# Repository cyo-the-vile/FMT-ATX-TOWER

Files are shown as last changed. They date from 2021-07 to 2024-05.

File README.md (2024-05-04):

# FMT-ATX-TOWER
A modification to revive a dead FM Towns tower model

[https://townsworld.com/2021/05/08/fm-towns-tower-power-supply-assembly-guide/](https://web.archive.org/web/20230320093739/https://townsworld.com/2021/05/08/fm-towns-tower-power-supply-assembly-guide/)

Uses an Arduino PRO Micro to control power on and TownsOS power off functions just like the original power supply.

Some of the mounting holes might not be exact.  At a later time, I need to measure the holes again but I don't own an original PCB anymore.  It is safe to file and cut around the screw points on the outer edges.

To order a PCB, go to factory output folder and select the RAR file.

Works on the following models:

1F
2F
SF
SH
1H
2H
10F
20F
40H
80H
SF2
SH2
CX10
CX20
CX40
CX100

It WILL NOT WORK for the following models:

S1
S2
MODEL1
MODEL2

You will need the following parts:

1    PCN13-44S-2.54DS
1	 39-28-1243    or you can use 39-28-1203.    It is preferred to use 39-28-1243
1    Arduino Pro Micro and Micro USB cable.  You need to load the firmware for the Arduino Pro Micro
1    Some male 2.54mm pin headers.
1    Pico PSU rated at 90W or higher such as this one   https://www.mini-box.com/picoPSU-90     The prototype was tested with 160W but I have found 90W is fine.
		Pico PSU have been cloned and their performance might vary. I recommend using the authentic mini-box brand.
1    AC/DC Converter.  The board can physically fit the EPS-120-12 or the EPS-120S-12.  Basically, an ACDC Converter that outputs 12V in a 2x3 or 2x4 (those are inches) form factor is fine.

日本人にとって、機械翻訳です。 あなたが困難を持っている場合は、Twitterで私に連絡してください。@cyothevile

死んだFMタウンズタワーモデルを復活させるための修正

[https://townsworld.com/2021/05/08/fm-towns-tower-power-supply-assembly-guide/](https://web.archive.org/web/20230320093739/https://townsworld.com/2021/05/08/fm-towns-tower-power-supply-assembly-guide/)

Arduino PRO Microを使用して、元の電源と同様に電源オンとTownsOSの電源オフ機能を制御します。

取り付け穴の中には、正確でないものもあります。 後で、私は再び穴を測定する必要がありますが、私はもう元のPCBを所有していません。 外縁のネジ点の周りをヤスリで留めて切断しても安全です。

PCBを注文するには、工場出荷時の出力フォルダに移動し、RARファイルを選択します。

次のモデルで動作します。

1F
2F
SF
SH
1H
2H
10F
20F
40H
80H
SF2
SH2
CX10
CX20
CX40
CX100

次のモデルでは動作しません。

S1
S2 
モデル1 or Model 1
モデル2 or Model 2

次の部品が必要です。

次の部品が必要です。

1 PCN13-44S-2.54DS
1 39-28-1243 または 39-28-1203 を使用できます。   39-28-1243 を使用することをお勧めします。
1 ArduinoプロマイクロとマイクロUSBケーブル。 Arduinoプロマイクロのファームウェアをロードする必要があります
1 いくつかのオス2.54mmピンヘッダー。
1 Pico PSUは、このような90W以上で定格 https://www.mini-box.com/picoPSU-90 プロトタイプは160Wでテストされましたが、90Wは問題ありません。
		Pico PSUはクローン化されており、それらのパフォーマンスは異なる場合があります。私は本物のミニボックスブランドを使用することをお勧めします。
1 AC / DCコンバータ。 ボードはEPS-120-12またはEPS-120S-12に物理的にフィットすることができます。 基本的に、2x3または2x4(これらはインチ)のフォームファクタで12Vを出力するACDCコンバータは問題ありません。

******************************************************

Generation 1 Tower card 

 - Requires more testing.  Should be safe for testing.

Please follow precise instructions here:  [https://townsworld.com/2021/06/01/fm-towns-power-supply-generation-1/](https://web.archive.org/web/20230603034252/https://townsworld.com/2021/06/01/fm-towns-power-supply-generation-1/)

VMS-180C-12
VOF-180C-12
VMS-200C-12

These are the recommended ACDC converters to place on the card.  The Generation 1 Towers appear to use more power.  A 160W Pico is recommended until further testing is completed.

ジェネレーション1タワーカード

日本人の友達、困ったら連絡してください。 TWITTER@cyo.the.vile

- さらにテストが必要です。テストのために安全でなければなりません。

こちらの正確な指示に従ってください: [https://townsworld.com/2021/06/01/fm-towns-power-supply-generation-1/](https://web.archive.org/web/20230603034252/https://townsworld.com/2021/06/01/fm-towns-power-supply-generation-1/)

VMS-180C-12
VOF-180C-12
VMS-200C-12

これらは、カードに配置する推奨 ACDC コンバータです。第 1 世代のタワーは、より多くの電力を使用しているようです。 さらなるテストが完了するまでは、160W Pico をお勧めします。

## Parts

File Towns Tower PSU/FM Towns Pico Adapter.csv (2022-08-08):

Id | Designator | Package | Quantity | Designation | Supplier and ref
1 | PAD1,PAD1,PAD1,PAD2,PAD1,PAD3,PAD4 | MountingHole_3.5mm_Pad_Via | 7 | MountingHole_3.5mm_Pad_Via
2 | U1 | ProMicro | 1 | ProMicro
3 | REF**,REF**,REF** | MountingHole_2.1mm | 3 | MountingHole_2.1mm
4 | REF**,REF**,REF**,REF**,REF**,REF** | MountingHole_4.3mm_M4 | 6 | MountingHole_4.3mm_M4
5 | STOCK_FAN | PinHeader_1x02_P2.54mm_Vertical | 1 | Conn_01x02
6 | J1 | ATX24_RIGHT_ANGLE | 1 | ATX24RH
7 | G*** | townslogo | 1 | LOGO
8 | J2 | PCN1344S254DS71 | 1 | PCN13-44S-2.54DS_71_

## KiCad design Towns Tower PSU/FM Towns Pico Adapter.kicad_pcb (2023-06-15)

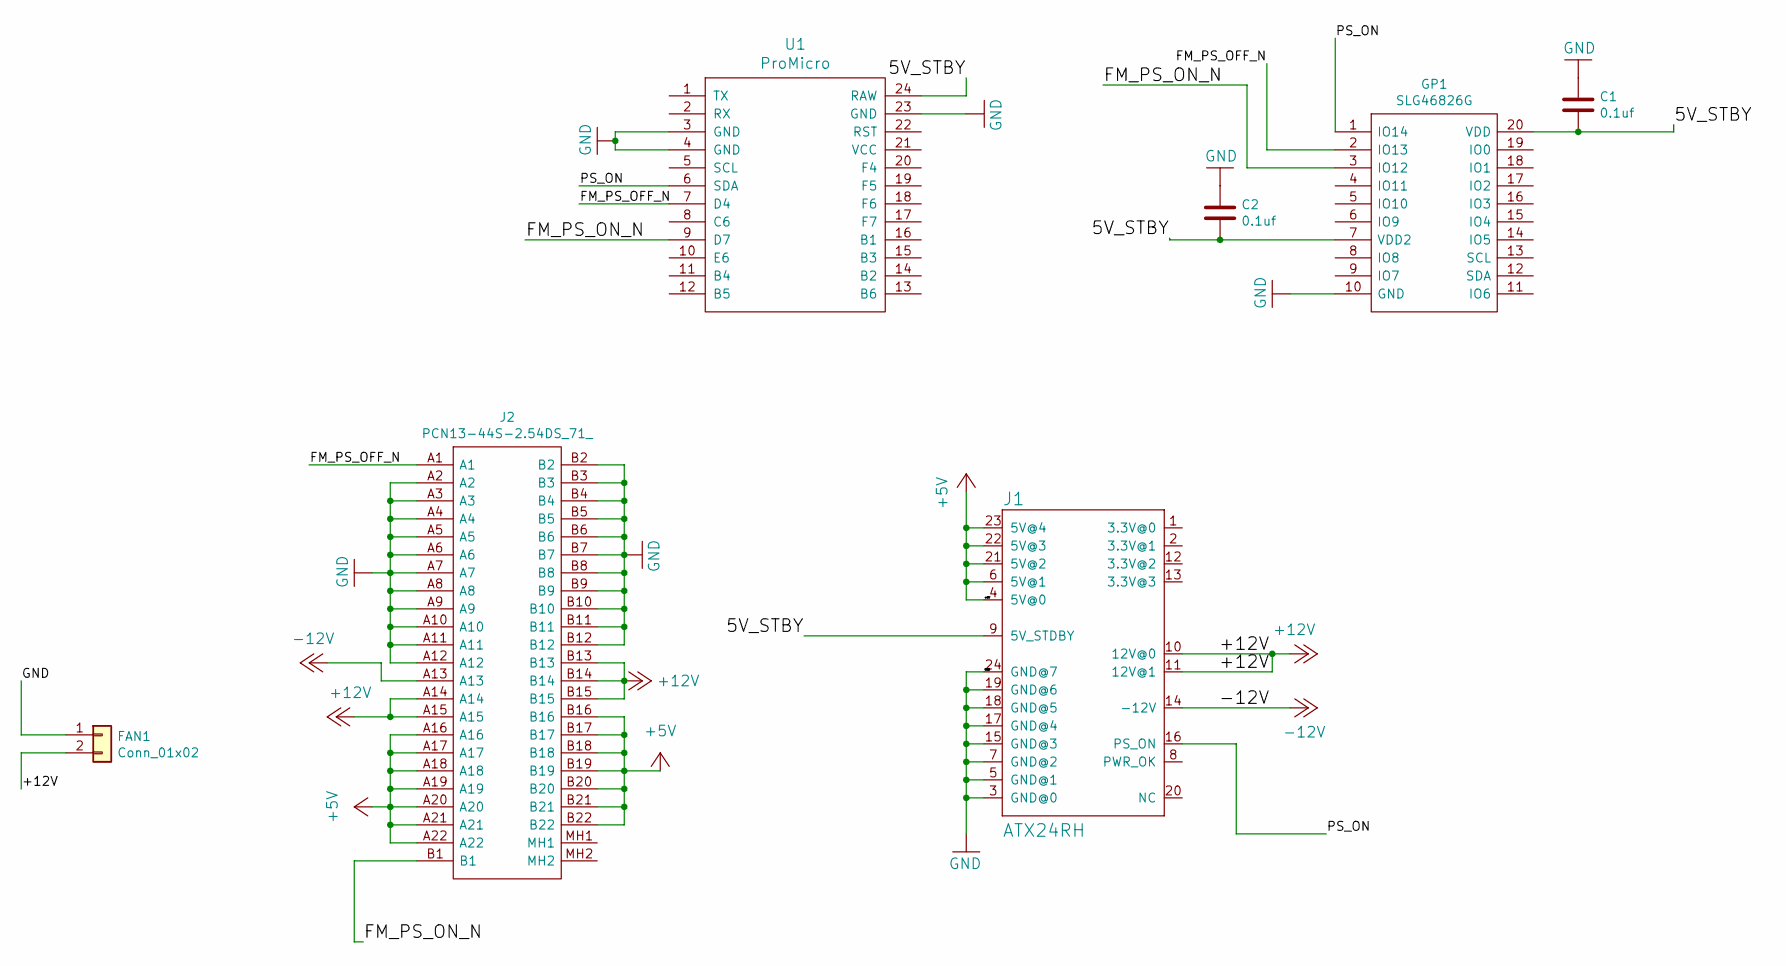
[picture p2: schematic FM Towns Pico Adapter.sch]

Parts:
C1, C2: 0.1uf; C_1206_3216Metric
FAN1: Conn_01x02; PinHeader_1x02_P2.54mm_Vertical
GP1: SLG46826G; SOP65P640X120-20N; Manufacturer_Part_Number SLG46826G; Mouser Part Number 724-SLG46826G
J1: ATX24RH; ATX24_RIGHT_ANGLE
J2: PCN13-44S-2.54DS_71_; PCN1344S254DS71; Manufacturer_Part_Number PCN13-44S-2.54DS(71); Mouser Part Number 798-PCN1344S254DS71
U1: ProMicro

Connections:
+5V: J1.4 (5V@0), J1.6 (5V@1), J1.21 (5V@2), J1.22 (5V@3), J1.23 (5V@4), J2.A16, J2.A17, J2.A18, J2.A19, J2.A20, J2.A21, J2.A22, J2.B16, J2.B17, J2.B18, J2.B19, J2.B20, J2.B21, J2.B22
+12V: FAN1.2, J1.10 (12V@0), J1.11 (12V@1), J2.A14, J2.A15, J2.B13, J2.B14, J2.B15
-12V: J1.14 (-12V), J2.A13
/5V_STBY: C1.2, C2.2, GP1.7 (VDD2), GP1.20 (VDD), J1.9 (5V_STDBY), U1.24 (RAW)
/FM_PS_OFF_N: GP1.2 (IO13), J2.A1, U1.7 (D4)
/FM_PS_ON_N: GP1.3 (IO12), J2.B1, U1.9 (D7)
/PS_ON: GP1.1 (IO14), J1.16 (PS_ON), U1.6 (SDA)
GND: C1.1, C2.1, FAN1.1, GP1.10 (GND), J1.3 (GND@0), J1.5 (GND@1), J1.7 (GND@2), J1.15 (GND@3), J1.17 (GND@4), J1.18 (GND@5), J1.19 (GND@6), J1.24 (GND@7), J2.A2, J2.A3, J2.A4, J2.A5, J2.A6, J2.A7, J2.A8, J2.A9, J2.A10, J2.A11, J2.A12, J2.B2, J2.B3, J2.B4, J2.B5, J2.B6, J2.B7, J2.B8, J2.B9, J2.B10, J2.B11, J2.B12, U1.3 (GND), U1.4 (GND), U1.23 (GND)

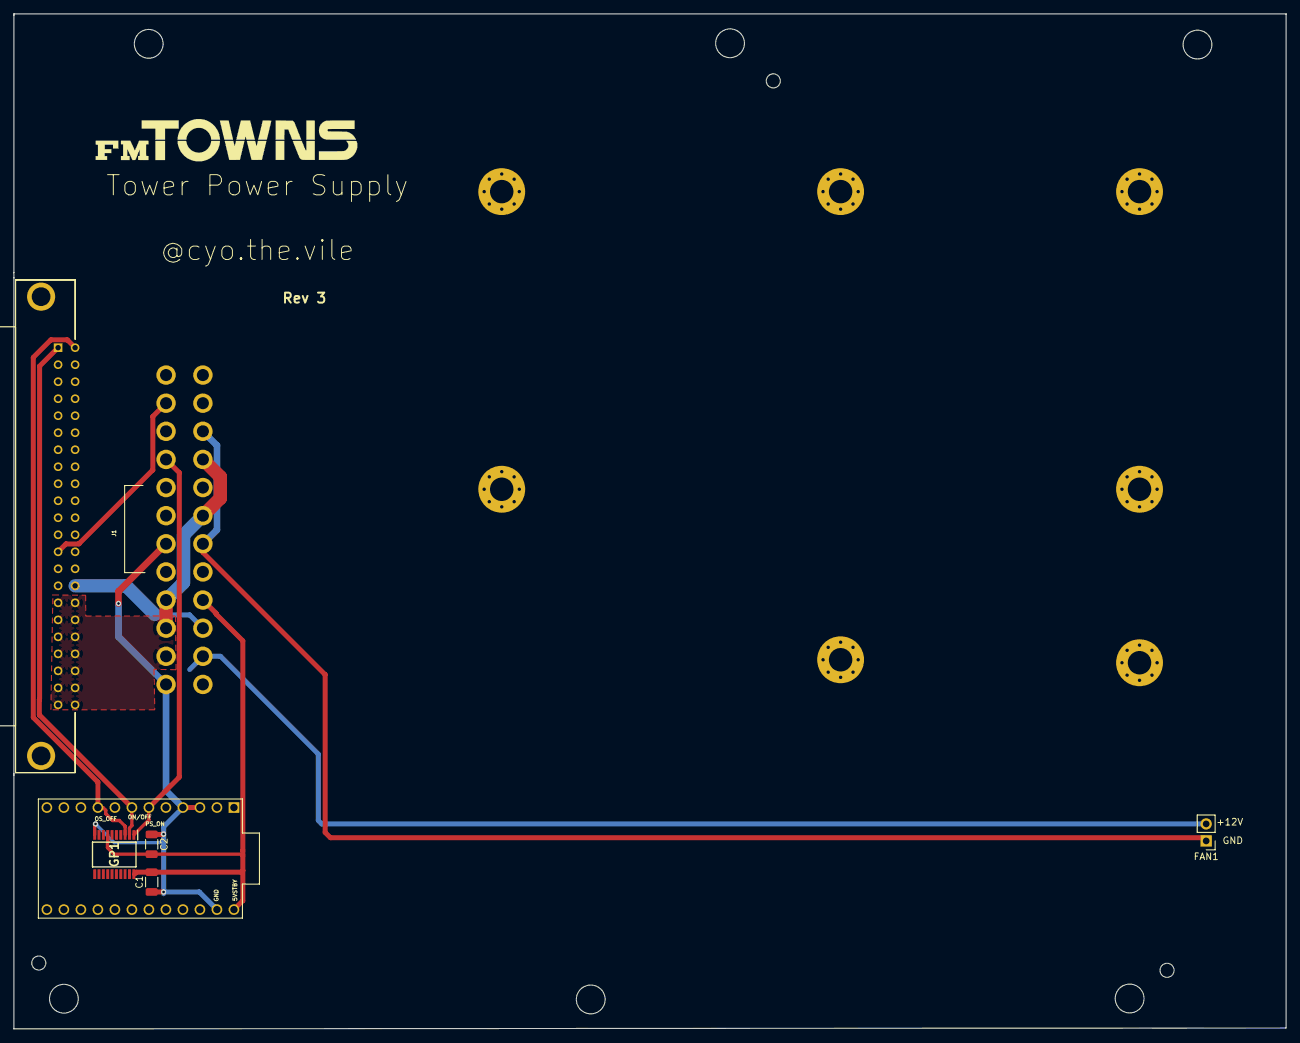
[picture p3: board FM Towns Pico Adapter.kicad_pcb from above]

Board: 2 copper layers, 190.0 x 151.6 mm, 14 parts (0 on the bottom side), 8 nets.

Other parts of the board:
PAD1, PAD1#2, PAD1#3, PAD1#4, PAD2, PAD3, PAD4: MountingHole_3.5mm_Pad_Via

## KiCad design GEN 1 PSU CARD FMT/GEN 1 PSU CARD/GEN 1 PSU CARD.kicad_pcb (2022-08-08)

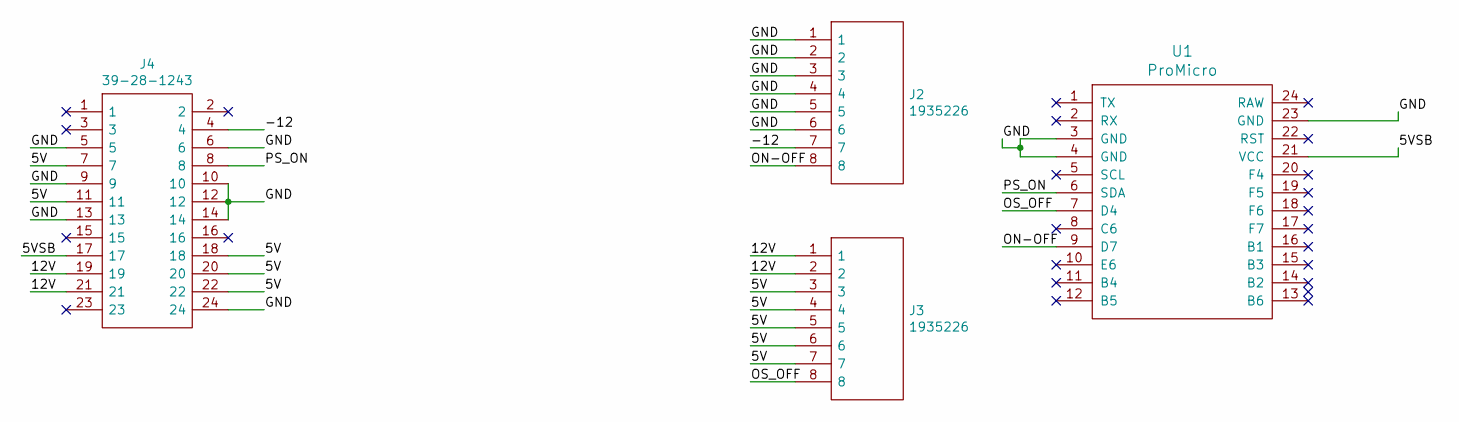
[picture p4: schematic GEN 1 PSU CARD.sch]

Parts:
J2, J3: 1935226; TerminalBlock_Phoenix_PT-1,5-8-3.5-H_1x08_P3.50mm_Horizontal; Manufacturer_Part_Number 1935226; Mouser Part Number 651-1935226
J4: 39-28-1243; SHDR24W125P550X420_2X12_5160X960X1310P; Manufacturer_Part_Number 39-28-1243; Mouser Part Number 538-39-28-1243
U1: ProMicro

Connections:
/5V: J3.3, J3.4, J3.5, J3.6, J3.7, J4.7, J4.11, J4.18, J4.20, J4.22
/5VSB: J4.17, U1.21 (VCC)
/12V: J3.1, J3.2, J4.19, J4.21
/-12: J2.7, J4.4
/GND: J2.1, J2.2, J2.3, J2.4, J2.5, J2.6, J4.5, J4.6, J4.9, J4.10, J4.12, J4.13, J4.14, J4.24, U1.3 (GND), U1.4 (GND), U1.23 (GND)
/ON-OFF: J2.8, U1.9 (D7)
/OS_OFF: J3.8, U1.7 (D4)
/PS_ON: J4.8, U1.6 (SDA)

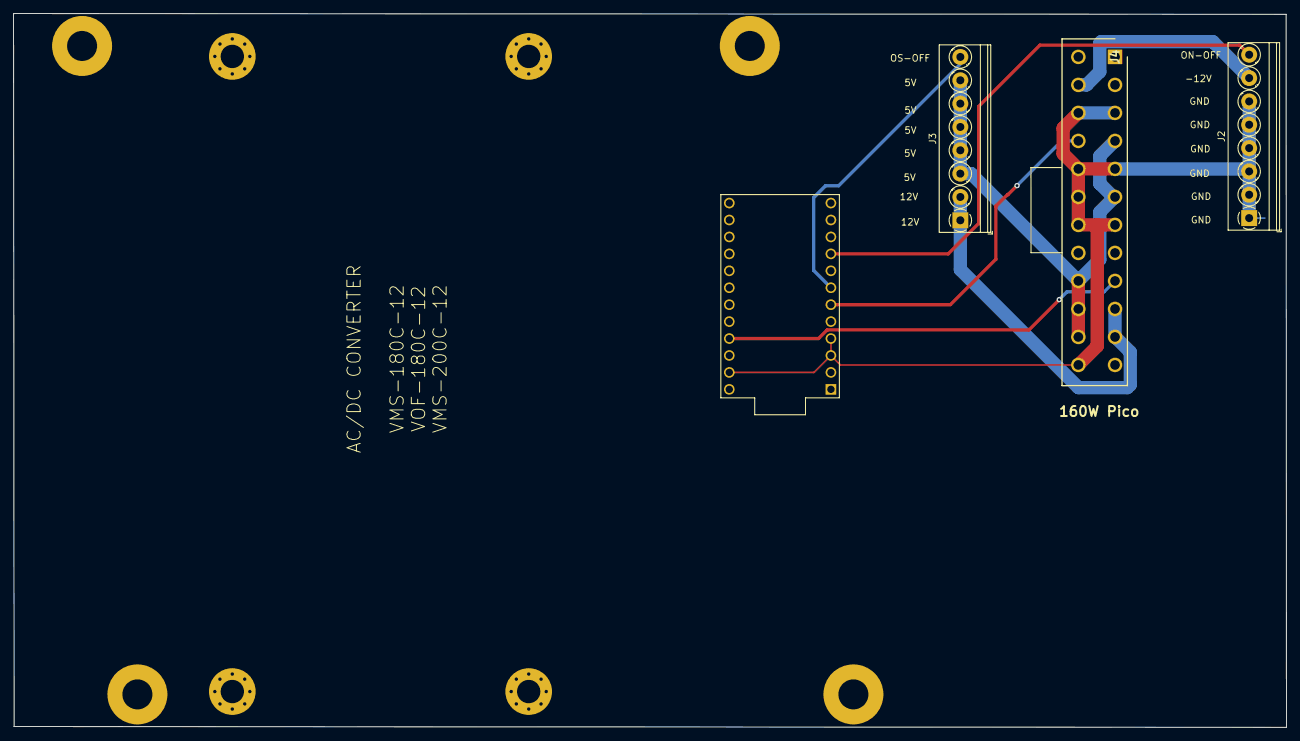
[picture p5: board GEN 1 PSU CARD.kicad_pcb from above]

Board: 2 copper layers, 190.9 x 107.1 mm, 4 parts (0 on the bottom side), 8 nets.

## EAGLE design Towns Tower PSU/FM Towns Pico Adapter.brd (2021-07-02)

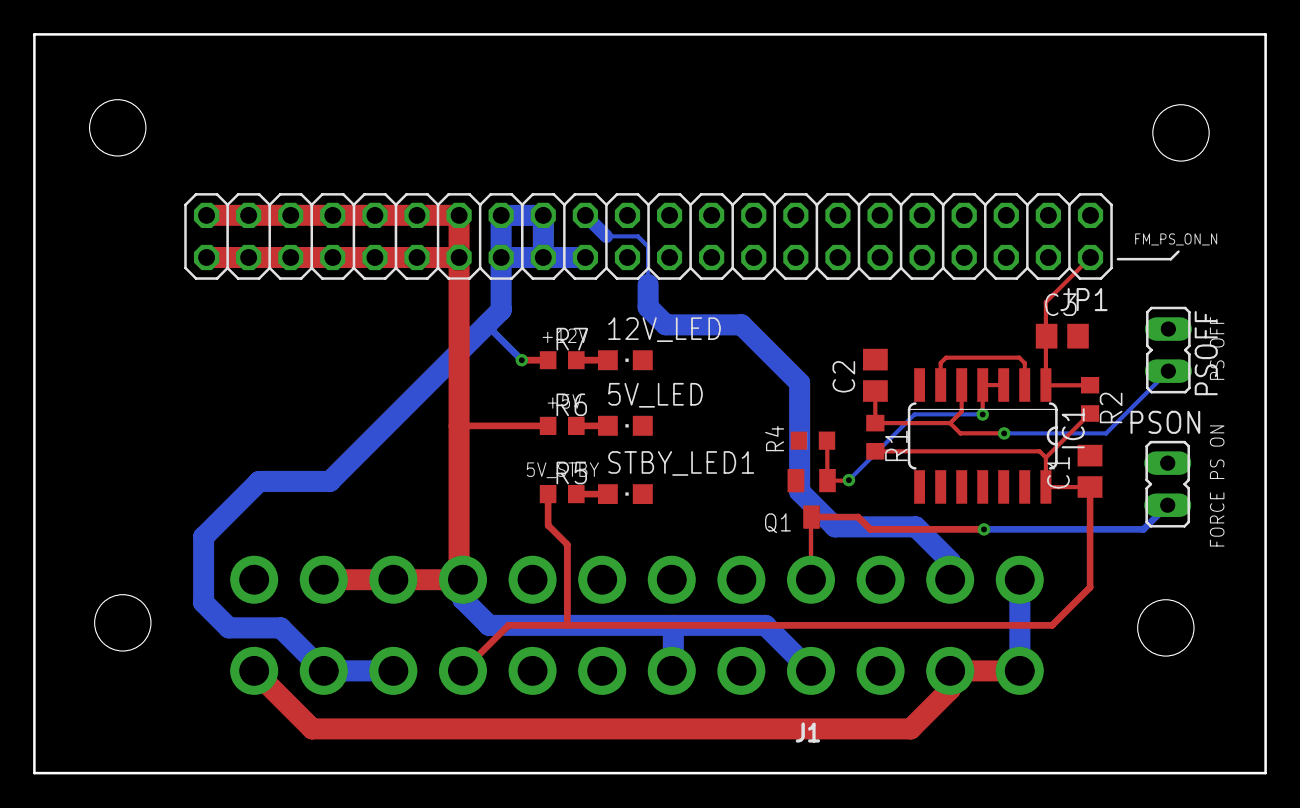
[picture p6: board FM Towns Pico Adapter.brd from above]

Board: 2 copper layers, 74.3 x 44.6 mm, 18 parts (0 on the bottom side), 14 nets.

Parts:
5V_LED, 12V_LED: CHIPLED_0805
C1, C2, C3: 100nF; C0805
IC1: 74HC00D; SO14
J1: ATX24RH; ATX24_RIGHT_ANGLE
JP1: 2X22
PSOFF: JP1
PSON: JP1
Q1: BC847; SOT23
R1, R2, R4: 1K; R0603
R5, R6: 220R; R0603
R7: 680R; R0603
STBY_LED1: CHIPLED_0805

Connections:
5V_STBY: C1.1, IC1.14, J1.9, R1.2, R2.2, R5.1
+3V3: J1.1, J1.2, J1.12, J1.13
+5V: J1.4, J1.6, J1.21, J1.22, J1.23, JP1.31, JP1.32, JP1.33, JP1.34, JP1.35, JP1.36, JP1.37, JP1.38, JP1.39, JP1.40, JP1.41, JP1.42, JP1.43, JP1.44, R6.1
+12V: J1.10, J1.11, JP1.26, JP1.27, JP1.28, JP1.29, JP1.30, R7.1
-12V: J1.14, JP1.25
ATX_PS_ON_N: J1.16, PSON.1, Q1.3
FM_PS_OFF_N: C2.1, IC1.5, PSOFF.2, R1.1
FM_PS_ON_N: C3.1, IC1.1, JP1.2, R2.1
GND: 5V_LED.C, 12V_LED.C, C1.2, C2.2, C3.2, IC1.7, IC1.9, IC1.10, IC1.12, IC1.13, J1.3, J1.5, J1.7, J1.15, J1.17, J1.18, J1.19, J1.24, JP1.3, JP1.4, JP1.5, JP1.6, JP1.7, JP1.8, JP1.9, JP1.10, JP1.11, JP1.12, JP1.13, JP1.14, JP1.15, JP1.16, JP1.17, JP1.18, JP1.19, JP1.20, JP1.21, JP1.22, JP1.23, JP1.24, PSOFF.1, PSON.2, Q1.2, R4.1, STBY_LED1.C
unnamed: IC1.2, IC1.6
unnamed: R5.2, STBY_LED1.A
unnamed: 5V_LED.A, R6.2
unnamed: 12V_LED.A, R7.2
PS_ON_TTL: IC1.3, IC1.4, Q1.1, R4.2

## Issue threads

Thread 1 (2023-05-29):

Screw holes, alignmemt pin holes, fan power pins, and overall pcb width do not match model 20F

SamBushman, 2023-05-29:

SamBushman, 2023-05-29:
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
Attached is a photo of
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
the board failing to align on one side and the fan power port being misaligned relative to the exhast fan frame

SamBushman, 2023-05-29:
I'll hold onto my original power supply PCB. Lmk if it would be helpful to make it available

cyo-the-vile, 2023-05-29:
This isnt true at all because the original card was based on a 20F I ripped
apart. Its been used on gen 2, 3 and 4 units. You might find a single hole
might not line up perfectly but Ive done 4 board revisions at this point
trying to line up holes. In recent install only 1 single hole was
problematic.

Use a 2.54mm header instead of recycling the original fan connector.  Check
the photos here.

https://townsworld.com/2021/05/08/fm-towns-tower-power-supply-assembly-guide/

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

SamBushman, 2023-05-29:
I don't if maybe the Towns had multiple power supplies manufactured or something, but looking at one of the PCBs I had made, it is clearly wider than the original power supply board.
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

If it helps, here is a picture of the power supply board's identification:
![Uploading 0529230707_HDR.jpg…]()

cyo-the-vile, 2023-05-29:
Dude it doesnt matter; my board works.

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

SamBushman, 2023-05-29:
Electricly it does, and its been great in that regard. I'm just trying to provide feedback for the experience I had putting it together to help improve the design.

Closed 2023-06-15.

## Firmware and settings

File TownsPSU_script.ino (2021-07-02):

String chkDiv = "off";

int pushPin = 4;    //Solder this wire to POWER ON-OFF Button on Towns

int psonPin = 3;    //Soldier this wire to PS_ON line of ATX Power Supply

int osPin = 6;      //Soldier this wire to OFF Wire on Towns Power Supply for TownsOS power off

 

void changePower(){

    if(chkDiv == "off"){

        digitalWrite(psonPin, LOW);

        chkDiv = "on";

    }else{

        digitalWrite(psonPin, HIGH);

        chkDiv = "off";

    }

}

void setup(void) {

    pinMode(pushPin, INPUT_PULLUP); //Power Switch Button

    pinMode(osPin, INPUT_PULLUP); //OS Power Button 

    pinMode(psonPin, OUTPUT); //ATX Power On off

    digitalWrite(psonPin, HIGH);

}

 

void loop(void) {

    if (digitalRead(pushPin) == LOW) {

        changePower();

        delay(500); 

    }else if (digitalRead(osPin) == LOW) {

        changePower();

        delay(500); 

}
}

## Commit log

2021-07-06 GEN1 card
    Generation 1 card changes
    [GEN 1 PSU CARD-B_Cu.gbr, GEN 1 PSU CARD-B_Mask.gbr, GEN 1 PSU CARD-B_Paste.gbr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]
2022-08-08 Rev2
    -Remeasured and added support holes for the ACDC converters in 2x4 form factor
    -Verification of original mounting holes is still required
    [FM Towns Pico Adapter-B_Mask.gbr, FM Towns Pico Adapter-B_Paste.gbr, FM Towns Pico Adapter-B_SilkS.gbr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]
2022-08-08 Gen 1 Card update
    -Revised Gen1 card and added high power ACDC converter footprint and repositioned components so it's two layer.
    [GEN 1 PSU CARD-B_Cu.gbr, GEN 1 PSU CARD-B_Mask.gbr, GEN 1 PSU CARD-B_Paste.gbr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]
2022-08-08 Update
    Updated Rev2
    Now 2 Layer card
    [GEN 1 PSU CARD-B_Cu.gbr, GEN 1 PSU CARD-B_Mask.gbr, GEN 1 PSU CARD-B_Paste.gbr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]
2023-06-15 TownsPSU Rev3
    -SLG62686 footprint added. Will add configuration file once verified on hardware although I don't see anyone using them.
    -Moved fan connector since someone complained
    [FM Towns Pico Adapter-B_Mask.gbr, FM Towns Pico Adapter-B_Paste.gbr, FM Towns Pico Adapter-B_SilkS.gbr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]

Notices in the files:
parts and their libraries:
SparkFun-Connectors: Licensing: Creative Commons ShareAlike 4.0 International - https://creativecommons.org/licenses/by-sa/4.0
